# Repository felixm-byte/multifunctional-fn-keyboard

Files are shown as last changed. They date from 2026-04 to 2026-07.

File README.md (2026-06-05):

# multifunctional-fn-keyboard
A function keyboard that is also a retro-style game controller. Switch modes, display button mappings or (soon) cool graphics on the colour display, and connect to any USB device. Includes accelerometer/gyroscope for natural-feeling motion controls in games.
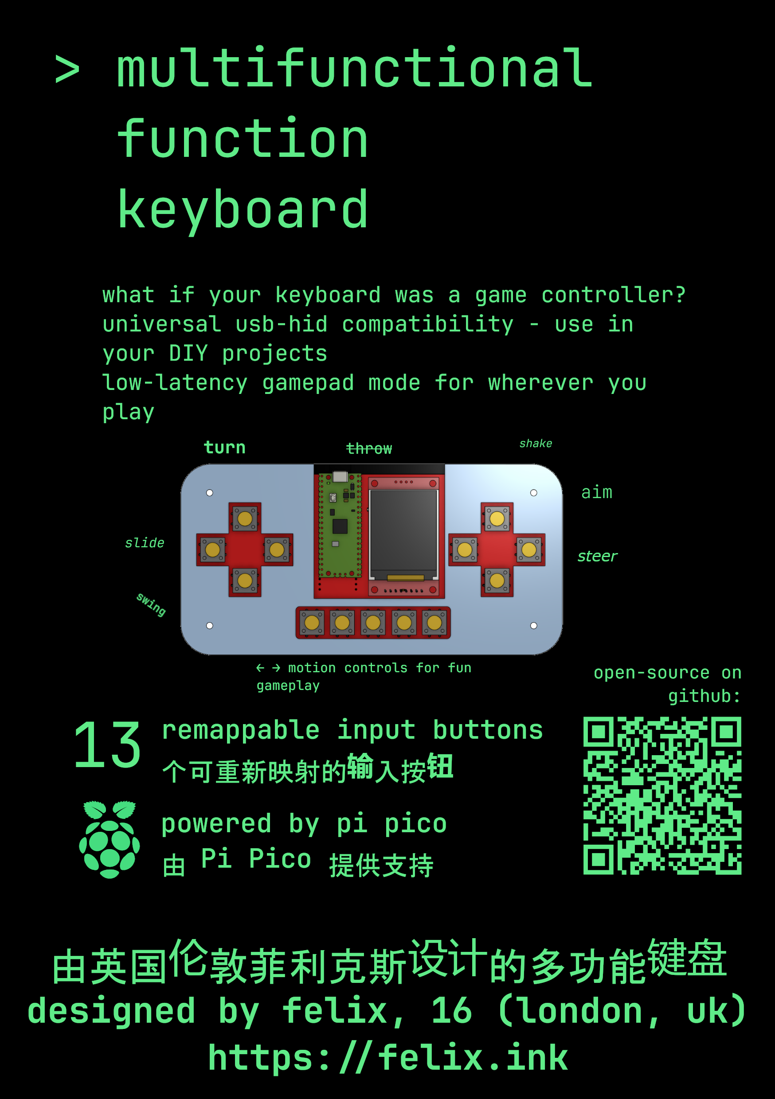
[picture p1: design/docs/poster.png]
a poster explaining features of the device, a photo and text in English and Simplified Chinese


Schematic diagram showing the wiring of pins on the Pi Pico.
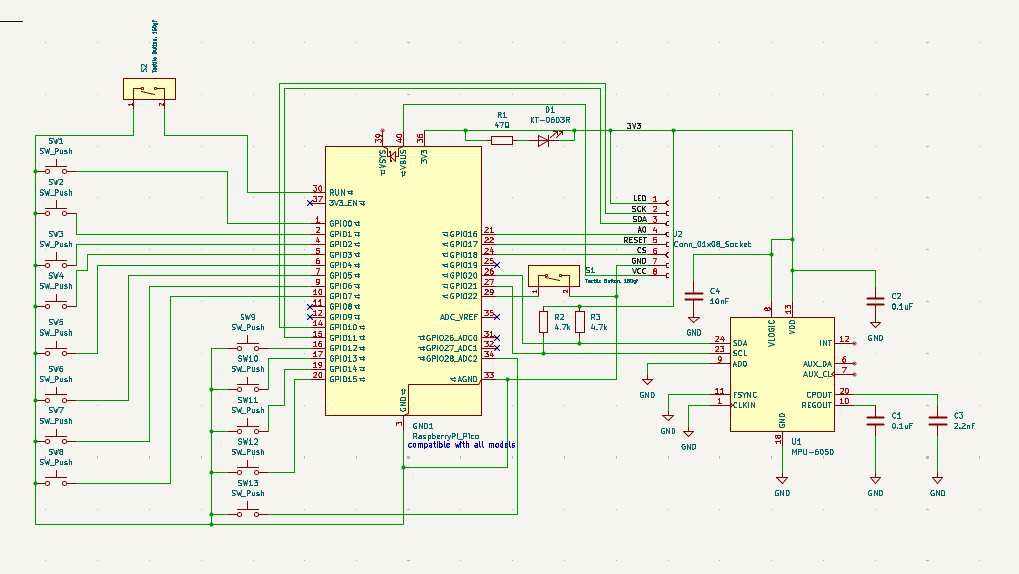
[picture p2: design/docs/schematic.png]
Schematic diagram

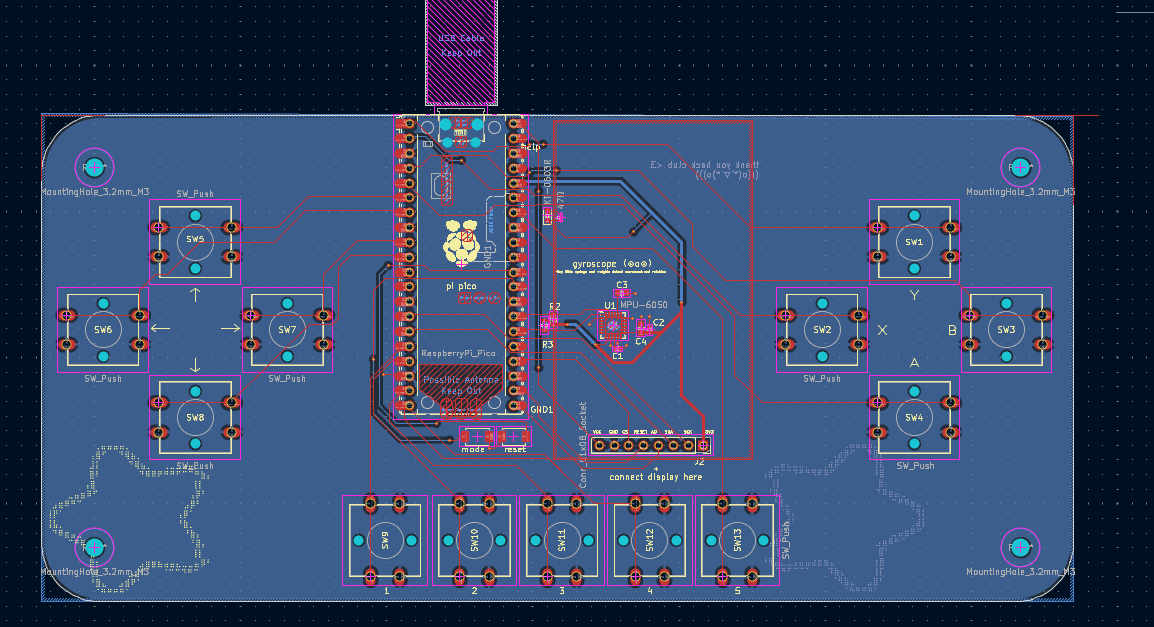
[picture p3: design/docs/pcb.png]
PCB render


## Inspiration
I've always thought a little remappable keyboard would be super useful for input in DIY projects, to easily test USB input, and I love the GameCube controller's middle screen and wanted to design games around it, so I decided to build this project to combine those 2 goals. Once I build the physical model, I will test out multi-key input for deeper shortcuts within apps, to make it also work as a function keyboard. I also have a built-in accelerometer/gyroscope, which will make for fun features and interactions in games and potentially also for software shortcuts.

# Design note
The controller works better without button-caps since the buttons can be directly exposed. This means I need one less part and one less supplier, making the design cheaper and simpler, and it is fine to expose buttons directly from the PCB, which is done in products like Hack Club Sprig.

# Parts
- Display: [ST7735 LCD display from Aliexpress, "1.8 TFT NO TOUCH" version](https://www.aliexpress.com/item/4000219159401.html)
- Microcontroller: Pi Pico 2 (definitely compatible with 2W, probably also with original series Picos)
- Refer to [ibom.html](design/bom/ibom.html) for interactive bill of materials 
- all other parts listed with LCSC part numbers in design/production/bom.csv
- PCB parts: £14.70 (backorder or JLCPCB idle parts) + £3 (display + screws)
- 3D printed parts
- 4xM3 16mm [(pan-head) screws with nyloc ends](https://www.aliexpress.com/item/1005012276006033.html)
- I have included a seperate document with links (bom-links.csv) for ease of purchasing, but it is probably best to get all parts except the Pi Pico using the JLCPCB assembly service.
- Total part cost: ~£18 (excluding PCB production and case 3D printing)

# Renders
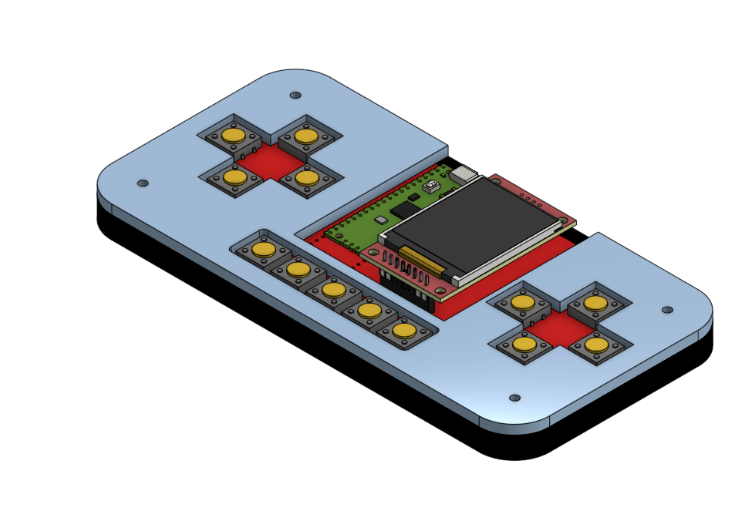
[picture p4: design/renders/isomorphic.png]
product isomorphic render

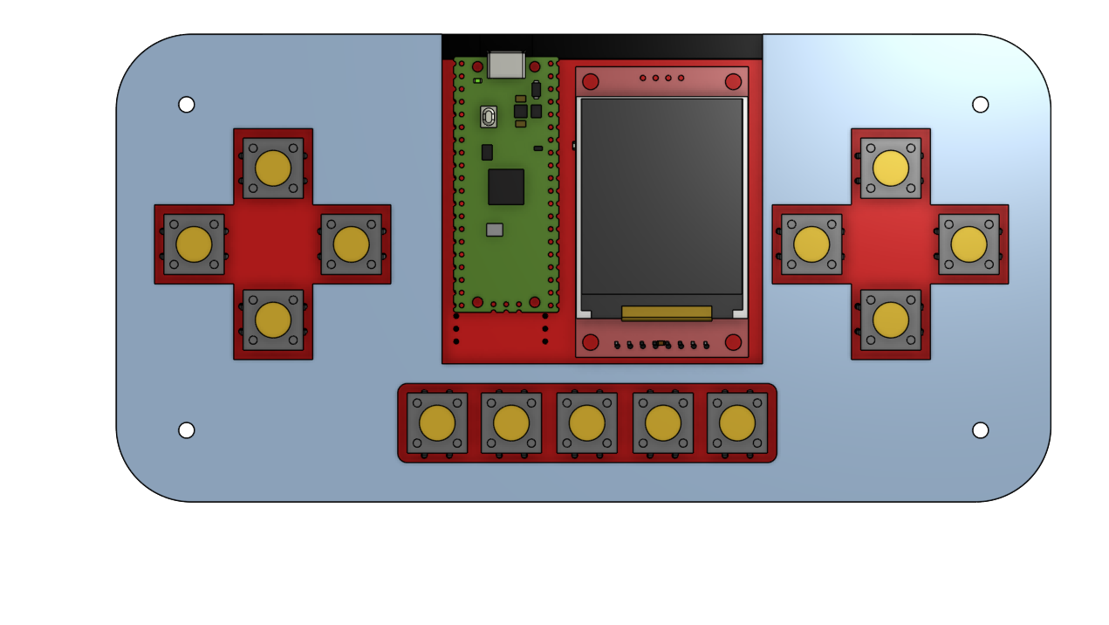
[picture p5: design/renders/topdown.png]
product top-down render

For demonstration only - colour and look will vary based on PCB manufacturing and colour used.

# Details
- Runs on MicroPython - you need to [install this on the Pi Pico](https://www.raspberrypi.com/documentation/microcontrollers/micropython.html) before installing main.py, mappings.kb and gamepad_mappings.kb (the content of the mappings files can be the same, but you need one mappings.kb and one gamepad_mappings.kb for the firmware to run)  
- Uses basic USB keyboard inputs (currently - additional feature implementation in progress) so universally compatible with devices supporting USB HID
- Designed in KiCad (PCB) and [OnShape (case) - click to open source files](https://cad.onshape.com/documents/51850c34b98423dfb69681d3/w/19fcd9cddc7b2960ac2d3a69/e/14cd91361d094cded8dbd10b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), use these programs to open or edit.

# Setup guide
- Get together all of the parts listed in the parts list (the 3D-printed shell is optional but strongly recommended for safety and comfort).
- To get all of the parts I will manufacture the PCB using a service like JLCPCB using the Gerber source file (design/gerber.zip), purchase parts using the bom.csv file which can be uploaded directly to LCSC for convenience. It could be more cost-effective to buy a Pi Pico 2 from a local source than LCSC. I would recommend you do something similar.
- Solder on all parts as shown in diagrams, including the Pi Pico (2) which should be soldered onto the PCB. The soldering should be moderate/medium difficulty, but I have not assembled it yet myself. Alternatively, use a PCB-assembly service like JLCPCB (notes in PCB assembly section).
- (optional) design/production/case-(bottom/top).stl are the 3D printing file for the case. 3D print the case in 2 seperate parts and use M3 16mm screws and nyloc nuts to attach it to the PCB, by placing the PCB into the slots in the bottom (larger) part of the case, inserting the screws through from the bottom, placing the top part of the case (which has cross cutouts for the button layouts) above the PCB and using the nyloc part to secure the screws from the top.
- (optional) Set up a custom .kb mappings file using the setup.py tool, ensure it is named mappings.kb or gamepad_mappings.kb for its use.
- Install main.py along with required micropython libraries (from external libraries section of readme), and .kb files, to the Pico.
- Connect to the device via USB. Press one button along with the HELP button to see what a button is mapped to. Hold down the 1,2,3,4&5 buttons simultaneously to switch from gamepad to keyboard mode (this leads to changed latencies for the specific use).

# PCB assembly
- If you would prefer not to assemble the PCB by hand, I would recommend using a PCB assembly service, especially for the small parts that can be placed cheaply by this service.
- I made an effort to minimise the number of parts used that are outside the JLCPCB basic library, so that the model can be assembled affordably using the JLCPCB PCBA service, which charges a US$3 fee per JLCPCB 'extended' part used.
- Some parts like the Pi Pico itself are non-machine-solderable (JLCPCB charges much extra for them) so I would recommend soldering them yourself, but you can pay the extended manufacturing surcharge and a series of $3 'extended parts' fees to have it fully assembled if that suits you better.
- Please let me know if there are any JLCPCB basic parts that could be used as substitutes so I can integrate them into the design, but I have looked quite deeply into this so I doubt there are any.
- I have chosen the B3F-4000 switches because of their much greater number of cycles (3 million vs 100 thousand) which is important for a keyboard that would be used regularly. Feel free to substitute this to suit your usecase.

# References
- https://www.youtube.com/watch?v=KaGHxvVnKQ4 (1:24 for display pinout explanation)
- https://github.com/alastairhm/micropython-st7735 for MicroPython display driver - this library needs to be installed on the Pi Pico
- https://github.com/micropython/micropython-lib/tree/master/micropython/usb -  MicroPython HID implementation
- https://cad.onshape.com/documents/51850c34b98423dfb69681d3/w/19fcd9cddc7b2960ac2d3a69/e/14cd91361d094cded8dbd10b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 OnShape source files

# External libraries
- https://github.com/alastairhm/micropython-st7735/tree/main - SPI TFT with ST7735 Driver library for Raspberry Pi Pico Micropython
- https://how2electronics.com/interfacing-mpu6050-with-raspberry-pi-pico-micropython/ - simple SPI driver for mpu6050 gyroscope

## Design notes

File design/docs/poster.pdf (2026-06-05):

# > multifunctional function

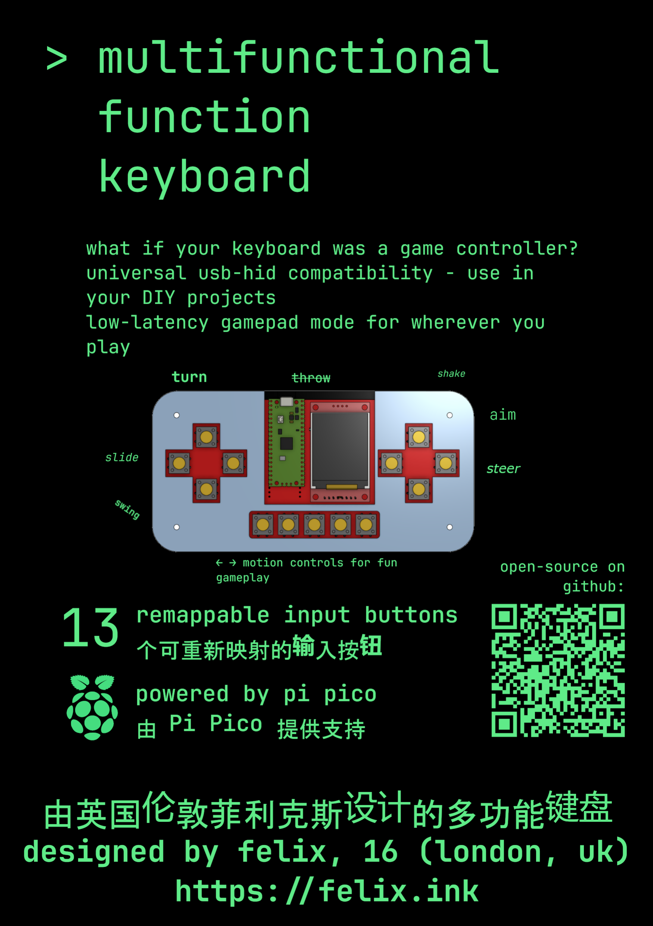
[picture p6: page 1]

# keyboard

what if your keyboard was a game controller? universal usb-hid compatibility - use in your DIY projects
low-latency gamepad mode for wherever you play
full-colour display

← → motion controls for fun gameplay

shake

slide

aim

throw

steer

turn

open-source on
github:

powered by pi pico
由 Pi Pico 提供支持

remappable input buttons 13 个可重新映射的输入按钮

## 由英国伦敦菲利克斯设计的多功能键盘

### designed by felix, 16 (london, uk) https://felix.ink

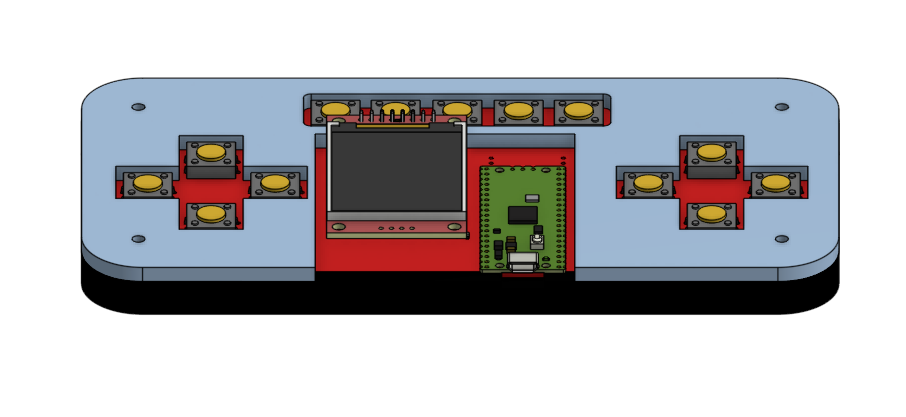
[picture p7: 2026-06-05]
design/renders/front-view.png

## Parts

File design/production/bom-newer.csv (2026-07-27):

Reference | Qty | Value | DNP | Exclude from BOM | Exclude from Board | Footprint | Datasheet | LCSC
C1,C2 | 2 | 100nF |  |  |  | Capacitor_SMD:C_0402_1005Metric |  | C307331
D1 | 1 | KT-0603R |  |  |  | LED_SMD:LED_0603_1608Metric |  | C2286
J2 | 1 | Conn_01x08_Socket |  |  |  | Connector_PinSocket_2.54mm:PinSocket_1x08_P2.54mm_Vertical |  | C27438
R1 | 1 | 47Ω |  |  |  | Resistor_SMD:R_0201_0603Metric |  | C23182
R2,R3 | 2 | 4.7k |  |  |  | Resistor_SMD:R_0603_1608Metric |  | C23162
S1,S2 | 2 | Tactile Button, 160gf |  |  |  | PCM_JLCPCB:SW_TS-1088-AR02016 | https://www.lcsc.com/datasheet/lcsc_datasheet_2304140030_XUNPU-TS-1088-AR02016_C720477.pdf | C720477
SW1,SW2,SW3,SW4,SW5,SW6,SW7,SW8,SW9,SW10,SW11,SW12,SW13 | 13 | SW_Push |  |  |  | Button_Switch_THT:SW_SPST_Omron_B3F-40xx |  | C87494
U1 | 1 | RaspberryPi_Pico |  |  |  | Module:RaspberryPi_Pico_Common_Unspecified | https://datasheets.raspberrypi.com/pico/pico-datasheet.pdf | C41407547
U2 | 1 | LIS2DW12 |  |  |  | LIS2DW12:LGA12R50P4X4_200X200X70 |  | C50385411

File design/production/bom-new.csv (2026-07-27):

Id | Designator | Footprint | Quantity | Designation | Supplier and ref
1 | C1, C2 | C_0402_1005Metric | 2 | 100nF
2 | D1 | LED_0603_1608Metric | 1 | KT-0603R
3 | J2 | PinSocket_1x08_P2.54mm_Vertical | 1 | Conn_01x08_Socket
4 | R1 | R_0201_0603Metric | 1 | 47Ω
5 | R2, R3 | R_0603_1608Metric | 2 | 4.7k
6 | S1, S2 | SW_TS-1088-AR02016 | 2 | Tactile Button, 160gf
7 | SW1, SW2, SW3, SW4, SW5, SW6, SW7, SW8, SW9, SW10, SW11, SW12, SW13 | SW_SPST_Omron_B3F-40xx | 13 | SW_Push
8 | U1 | LGA-14_3x2.5mm_P0.5mm_LayoutBorder3x4y | 1 | LSM6DS3
9 | U2 | RaspberryPi_Pico_Common_Unspecified | 1 | RaspberryPi_Pico

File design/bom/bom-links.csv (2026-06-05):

Item | Link | Per unit price | minimum order quantity
PCB components* | https://lcsc.com | œ3.19 | 5
MPU-6050 | https://www.aliexpress.com/item/1005007986741850.html | œ5.31 | 5
Pi Pico | https://thepihut.com/products/raspberry-pi-pico | œ3.80 | 1
Screw set (M3 16mm needed) | https://www.aliexpress.com/item/1005012276006033.html | œ2.91 | 4
Total |  | œ15.21
* excludes Pi Pico, MPU-6050

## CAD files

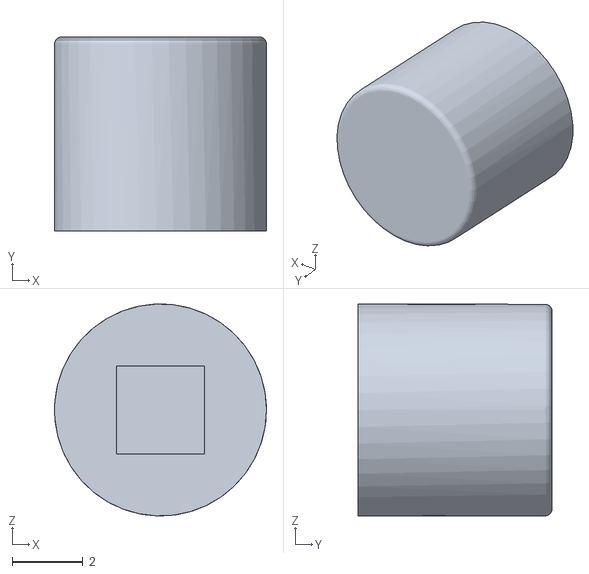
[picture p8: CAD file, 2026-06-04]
design/3d-source/b32-2010.stl
6.00 x 5.50 x 6.00

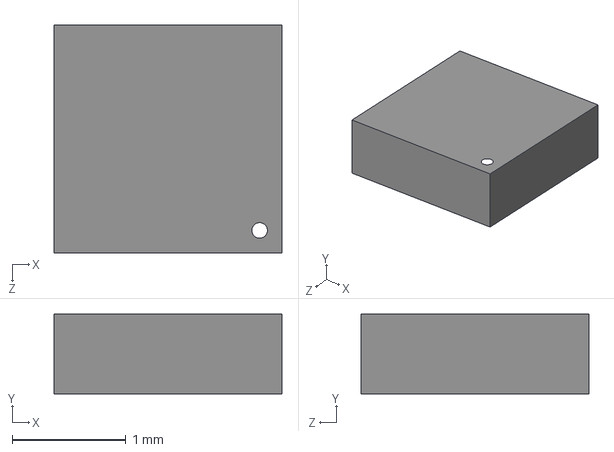
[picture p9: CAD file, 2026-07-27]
design/kicad-footprints/LIS2DW12/LIS2DW12.step
2.00 x 0.7 x 2.00 mm

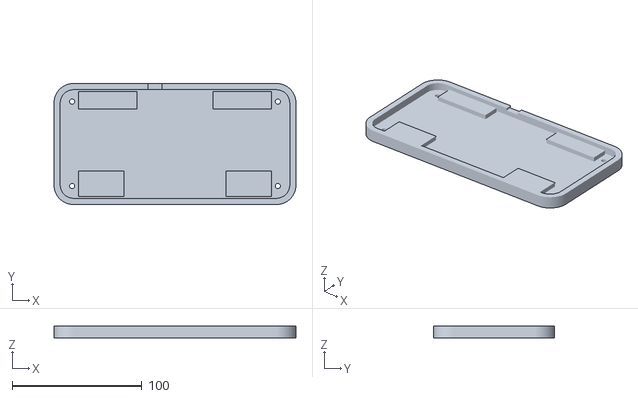
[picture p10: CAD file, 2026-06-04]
design/production/case-bottom.stl
186.5 x 93.2 x 9.30

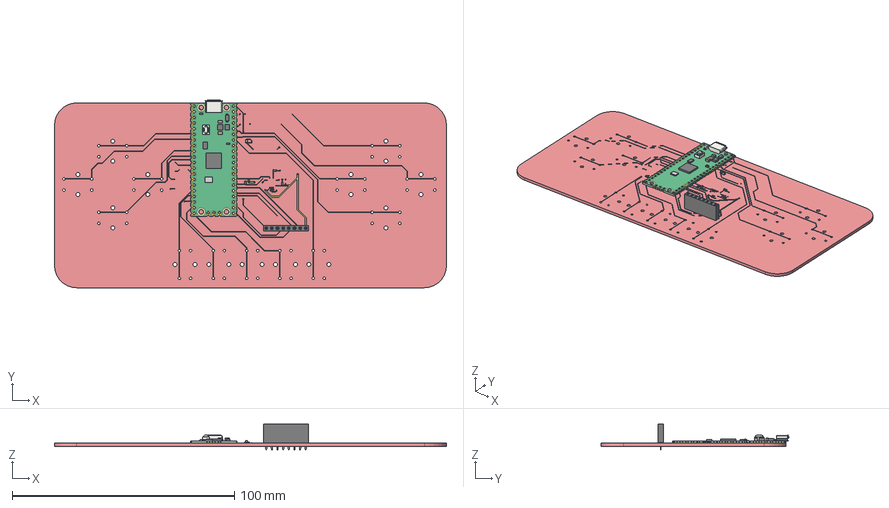
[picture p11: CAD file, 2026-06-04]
design/3d-source/pcb-model.step
176.5 x 84.5 x 11.6 mm
RaspberryPi_Pico_Module_KiCad
R_0201_0603Metric
C_0402_1005Metric x 2
R_0603_1608Metric x 2
LED_0603_1608Metric
C_0603_1608Metric x 2
PinSocket_1x08_P2.54mm_Vertical
design_copper
design_via
design_PCB

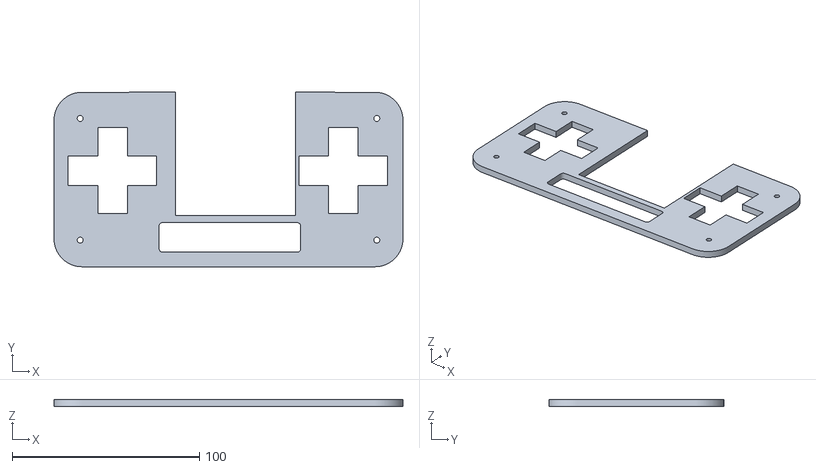
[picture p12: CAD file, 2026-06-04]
design/production/case-top.stl
186.5 x 93.3 x 4.00

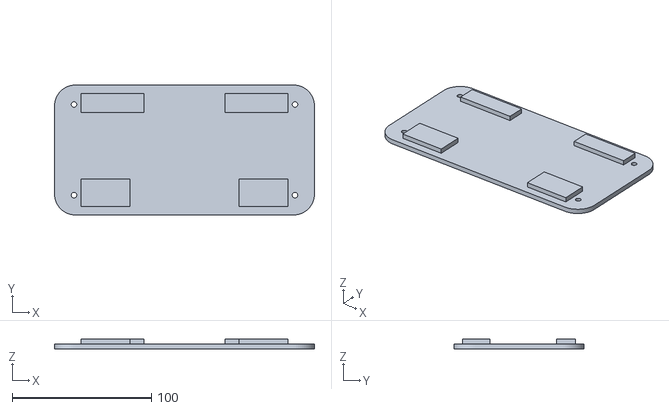
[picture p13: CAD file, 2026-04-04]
design/3d-source/base.stl
186.5 x 93.2 x 7.00

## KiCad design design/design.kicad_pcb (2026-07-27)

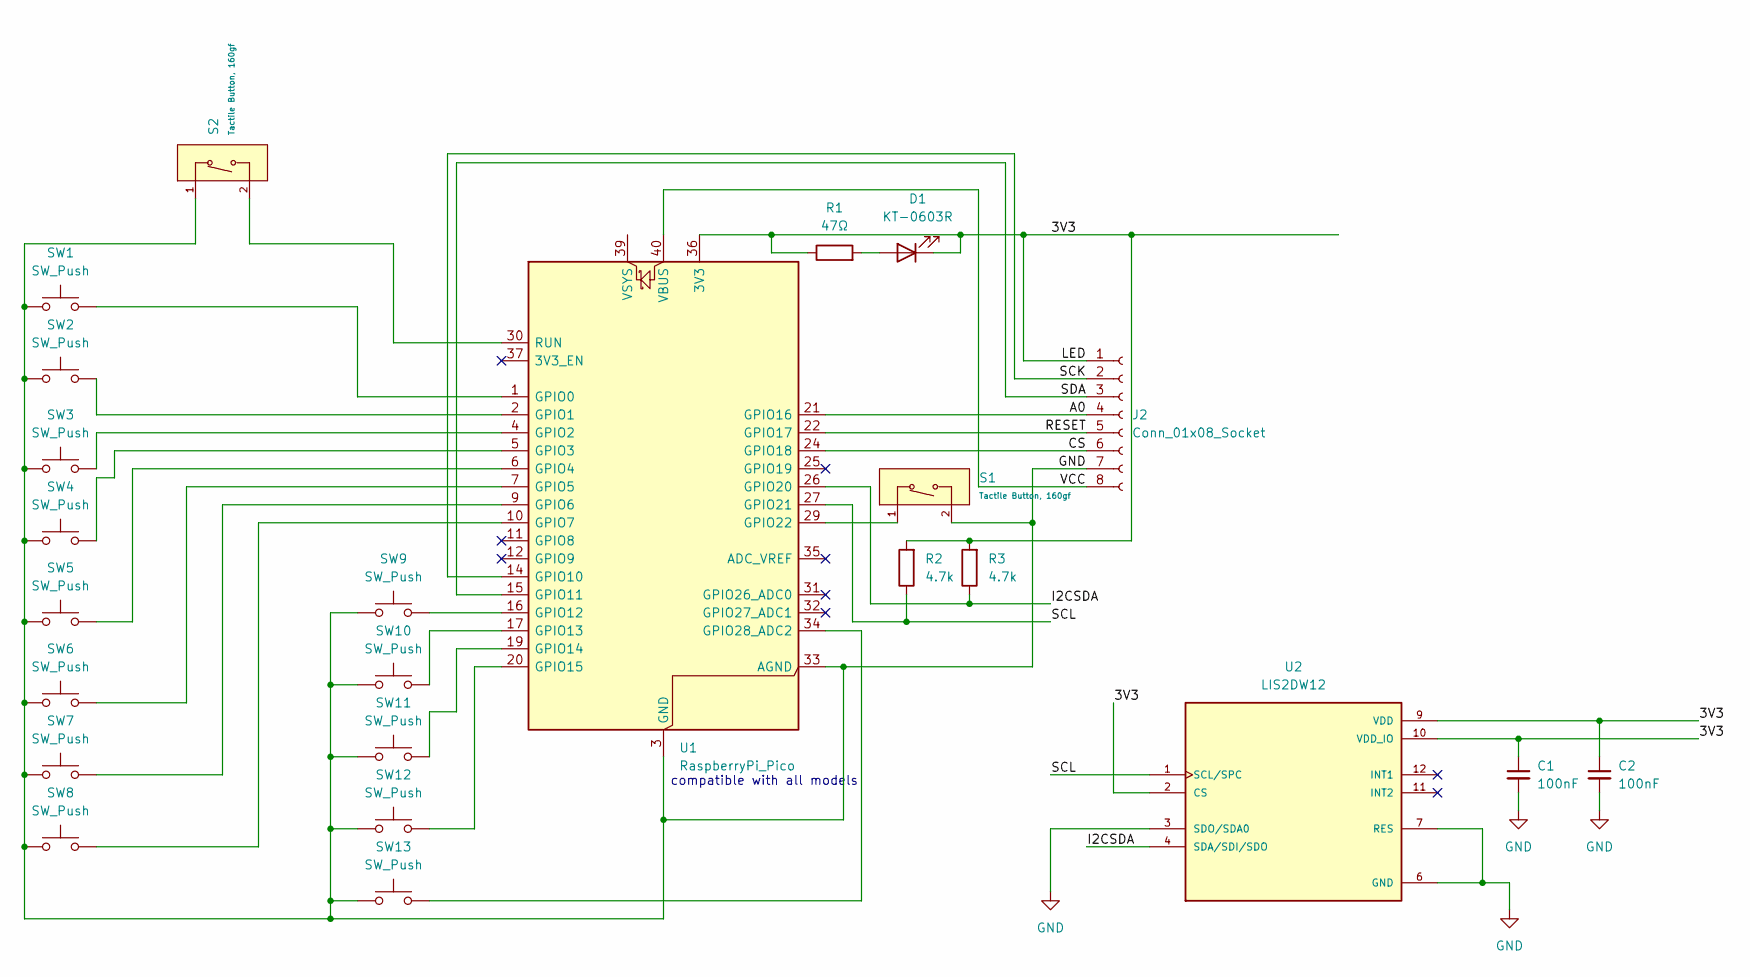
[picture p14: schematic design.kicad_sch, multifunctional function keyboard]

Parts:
C1, C2: 100nF; C_0402_1005Metric; LCSC C307331
D1: KT-0603R; LED_0603_1608Metric; LCSC C2286
J2: Conn_01x08_Socket; PinSocket_1x08_P2.54mm_Vertical; LCSC C27438
R1: 47Ω; R_0201_0603Metric; LCSC C23182
R2, R3: 4.7k; R_0603_1608Metric; LCSC C23162
S1, S2: Tactile Button, 160gf; SW_TS-1088-AR02016; Voltage Rating (Dc) 12V; Part TS-1088-AR02016; LCSC C720477
SW1, SW2, SW3, SW4, SW5, SW6, SW7, SW8, SW9, SW10, SW11, SW12, SW13: SW_Push; SW_SPST_Omron_B3F-40xx; LCSC C87494
U1: RaspberryPi_Pico; RaspberryPi_Pico_Common_Unspecified; LCSC C41407547
U2: LIS2DW12; LGA12R50P4X4_200X200X70; PARTREV 4; LCSC C50385411

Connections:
/3V3: C1.1, C2.1, D1.1 (K), J2.1, R1.1, R2.2, R3.2, U1.36 (3V3), U2.2 (CS), U2.9 (VDD), U2.10 (VDD_IO)
/A0: J2.4, U1.21 (GPIO16)
/CS: J2.6, U1.24 (GPIO18)
/I2CSDA: R3.1, U1.26 (GPIO20), U2.4 (SDA/SDI/SDO)
/RESET: J2.5, U1.22 (GPIO17)
/SCK: J2.2, U1.14 (GPIO10)
/SCL: R2.1, U1.27 (GPIO21), U2.1 (SCL/SPC)
/SDA: J2.3, U1.15 (GPIO11)
/VCC: J2.8, U1.40 (VBUS)
GND: C1.2, C2.2, J2.7, S1.2 (B), S2.1 (A), SW1.2, SW2.2, SW3.2, SW4.2, SW5.2, SW6.2, SW7.2, SW8.2, SW9.2, SW10.2, SW11.2, SW12.2, SW13.2, U1.3 (GND), U1.8 (GND), U1.13 (GND), U1.18 (GND), U1.23 (GND), U1.28 (GND), U1.33 (AGND), U1.38 (GND), U2.3 (SDO/SDA0), U2.6 (GND), U2.7 (RES), U2.8 (GND)
unnamed: D1.2 (A), R1.2
unnamed: S1.1 (A), U1.29 (GPIO22)
unnamed: S2.2 (B), U1.30 (RUN)
unnamed: SW1.1, U1.1 (GPIO0)
unnamed: SW2.1, U1.2 (GPIO1)
unnamed: SW3.1, U1.4 (GPIO2)
unnamed: SW4.1, U1.5 (GPIO3)
unnamed: SW5.1, U1.6 (GPIO4)
unnamed: SW6.1, U1.7 (GPIO5)
unnamed: SW7.1, U1.9 (GPIO6)
unnamed: SW8.1, U1.10 (GPIO7)
unnamed: SW9.1, U1.16 (GPIO12)
unnamed: SW10.1, U1.17 (GPIO13)
unnamed: SW11.1, U1.19 (GPIO14)
unnamed: SW12.1, U1.20 (GPIO15)
unnamed: SW13.1, U1.34 (GPIO28_ADC2)

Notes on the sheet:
compatible with all models

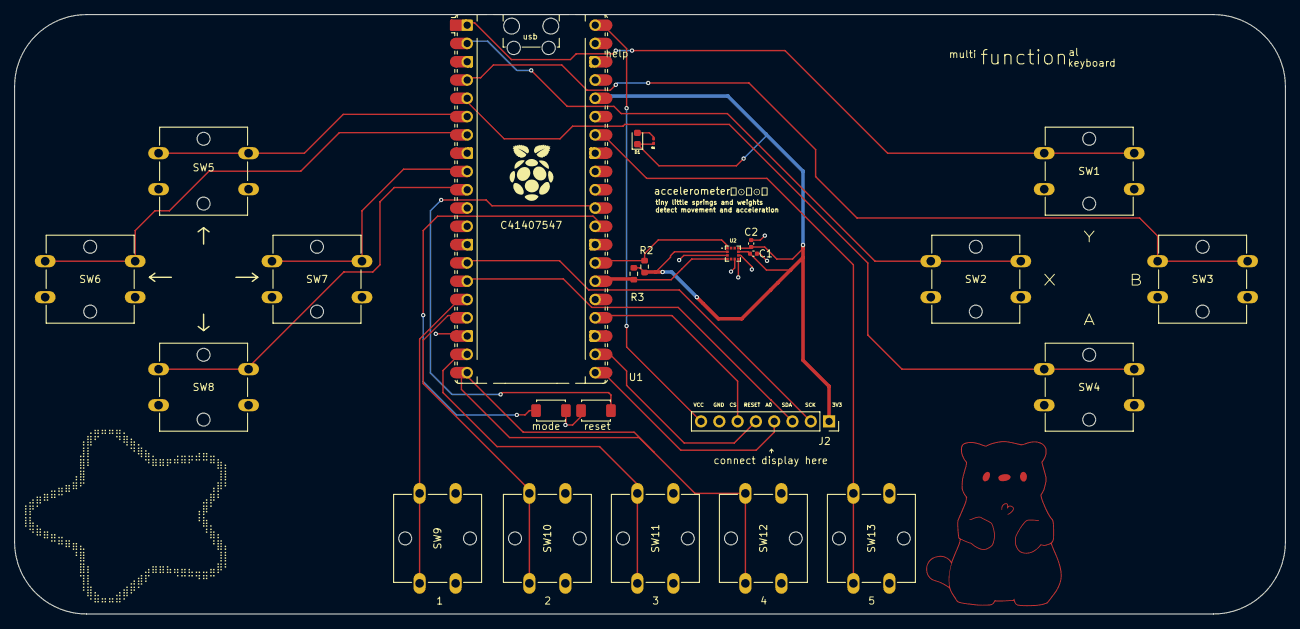
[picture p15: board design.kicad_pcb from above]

Board: 2 copper layers, 176.5 x 83.2 mm, 24 parts (0 on the bottom side), 26 nets.

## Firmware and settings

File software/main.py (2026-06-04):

import usb.device
from usb.device.keyboard import KeyboardInterface, KeyCode, LEDCode
from machine import Pin,SPI,I2C
import time
import pickle
from st7735 import TFT
from st7735 import sysfont
import math
import _thread
import gc
import mpu6050 as gyro

i2c_gyro = I2C(0, scl=Pin(21), sda=Pin(20), freq=400000)
spi = SPI(1, baudrate=20000000, polarity=0, phase=0, sck=Pin(10), mosi=Pin(11), miso=None) #mosi is the same as SDA
tft=TFT(spi,16,17,18)
tft.initr()
tft.rgb(True)


KEYS = (
    (Pin.CPU.GPIO0, "Y"),
    (Pin.CPU.GPIO1, "X"),
    (Pin.CPU.GPIO2, "B"),
    (Pin.CPU.GPIO3, "A"),
    (Pin.CPU.GPIO4, "UP"),
    (Pin.CPU.GPIO5, "LEFT"),
    (Pin.CPU.GPIO6, "RIGHT"),
    (Pin.CPU.GPIO7, "DOWN"),
    (Pin.CPU.GPIO12, "1"),
    (Pin.CPU.GPIO13, "2"),
    (Pin.CPU.GPIO14, "3"),
    (Pin.CPU.GPIO15, "4"),
    (Pin.CPU.GPIO28, "5")
) # verify with hardware, layout may change before production

#in this design the only LED is power, power is not connected to a GPIO pin

#the device has 2 modes - gamepad and function keyboard
#in function keyboard mode, people will not want signals to be sent multiple times even if they hold down the button - simplistic debouncing by giving a 1000ms wait until button is sent again
#in gamepad, people will want to hold down a button or mash repeatedly so a very short debouncing time should be used (20ms)
#the shortcut to switch to/from gamepad is holding down 1,2,3,4,5 simultaneously, which is almost impossible to fat finger but easy and memorable to do
REFRESH_TIME = 5
#bouncing times must be a multiple
GAMEPAD_BOUNCING_TIME = 20
KEYBOARD_BOUNCING_TIME = 1000

help_button = Pin.CPU.GPIO22
help_button.init(Pin.IN, Pin.PULL_UP)

for pin, _ in KEYS:
    pin.init(Pin.IN, Pin.PULL_UP)

class Keyboard(KeyboardInterface):
    pass #there is no custom keyboard functionality needed right now, change if needed in future

gamepad_mode = False 
keyboard = Keyboard()
mappings = {}; gamepad_mappings = {}

def display_help(keyname, keymapping):
    tft.fill(TFT.BLACK)
    v = 30
    tft.text((0, v), f"The key {keyname}", TFT.RED, sysfont, 1, nowrap=True)
    v += sysfont["Height"]
    tft.text((0,v), f"maps to {keymapping}", TFT.BLUe, sysfont, 2, nowrap=True)
    gc.collect()

def display_change_notice(is_in_gamepad_mode):
    tft.fill(TFT.BLACK)
    v = 30
    tft.text((0, v), f"Gamepad mode:", TFT.RED, sysfont, 1, nowrap=True)
    v += sysfont["Height"]
    tft.text((0, v), f"Turned {"on" if is_in_gamepad_mode else "off"}.", TFT.RED, sysfont, 1, nowrap=True)
    gc.collect()

def load_mappings():
    global mappings
    global gamepad_mappings
    f = open("mappings.kb", 'rb')
    mappings = pickle.load(f)
    f = open("gamepad_mappings.kb", 'rb')
    gamepad_mappings = pickle.load(f)

def output_keys(ids):
    global gamepad_mode; global mappings
    keys = []
    if gamepad_mode:
        for id in ids:
            keys.append(mappings[id])
    keyboard.send_keys(keys)

usb.device.get().init(keyboard, builtin_driver=True)

previous_keys = [["none", 0], ["none, 0"]]
while True:
    if keyboard.is_open():
        keys = []
        active_keys = []
        for pin, id in KEYS:
            if not pin(): #pin must be 0 for keys to be active
                keys.append(id)
        #this may cause lag, better to cause output lag than missing keypresses
        if not help_button():
            new_thread = _thread.start_new_thread(display_help, (str(keys[0]), (gamepad_mappings if gamepad_mode else mappings)[keys[0]] ) )

        if keys == ["1", "2", "3", "4", "5"]:
            gamepad_mode = not gamepad_mode

        
        for k in range(len(previous_keys)):
            if previous_keys[k][1] + REFRESH_TIME >= (GAMEPAD_BOUNCING_TIME if gamepad_mode else KEYBOARD_BOUNCING_TIME):
                previous_keys.pop(k)
            else:
                previous_keys[k][1] += REFRESH_TIME
            
        for key_pressed in keys:
            for p in previous_keys:
                if not key_pressed == p[0]: #key has been previously pressed
                    previous_keys.append([key_pressed, 0])
                    active_keys.append(key_pressed)

        output_keys(keys)
    motion_data = gyro.get_mpu6050_data(i2c=i2c_gyro)
    print(motion_data['temp']) #later on i will write more advanced firmware to give the data back to the host computer, but for now it can just be kept.
    time.sleep_ms(REFRESH_TIME)
    


                

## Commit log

2026-04-03 Added mounting holes KiCad
    [design.kicad_pcb, design.kicad_sch, pcb-model.step]
2026-04-04 KiCad work, 3D modelling case
    [base.stl, bom.csv, bom2.csv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]
2026-04-04 Updated manufacturing files for JLCPCB
    [design.csv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]
2026-04-10 Final changes for production
    [bom.csv, bom2.csv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]
2026-04-11 Update readme with screw choice
2026-04-13 Dcoumentation, improved poster, production details
    [ManufacturedPart.stl]
2026-04-14 Reorganised file structure, interactive BOM
    [ManufacturedPart.stl, base.stl, bom.csv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]
2026-05-24 Adding gyroscope, redesigning PCB
    [design.kicad_pcb, design.kicad_sch, pcb_old.kicad_pcb]
2026-06-03 Added details on parts, added gyroscope to design
    [design.kicad_pcb, design.kicad_sch]
2026-06-04 Design updates and add MPU6050 driver
    Update KiCad PCB, gerbers and BOM; adjust STEP/3D model coordinates and add new 3D/production STL assets. Tidy repo by updating .gitignore and adding a VSCode setting. Remove outdated production bund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
    [ManufacturedPart.stl, b32-2010.stl, bom.csv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]
2026-06-05 Improved poster and renders, re-exported gerber file
    [design-B_Cu.gbr, design-B_Mask.gbr, design-B_Paste.gbr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]
2026-06-05 Updated readme, added BOM links
    [bom-links.csv]
2026-07-26 Updated PCB with style
    [design.kicad_pcb, design.kicad_sch]
2026-07-27 Version using LSM6DS3 (C967633) chip
    [bom-new.csv, bom-newer.csv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]
2026-07-27 Redesigned to use clone accelerometer module
    [LIS2DW12.step, bom-newer.csv, bom.csv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]
